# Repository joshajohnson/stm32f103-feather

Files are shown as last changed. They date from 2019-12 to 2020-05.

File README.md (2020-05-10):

# STM32F103 Feather

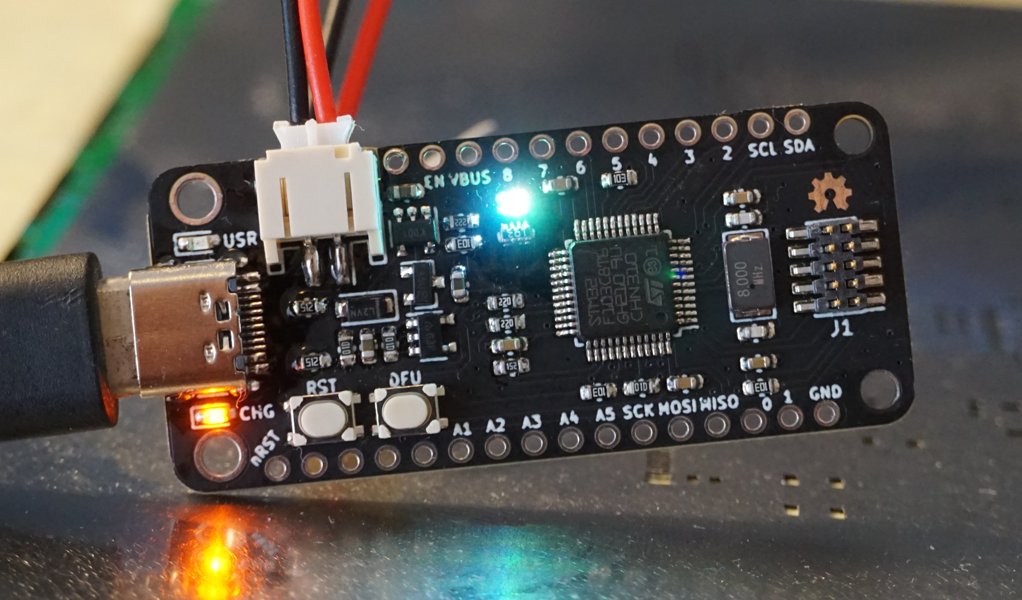
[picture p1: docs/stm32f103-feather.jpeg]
STM32F103 Feather


## STM32F103 in an Adafruit Feather form factor.
- STM32F103 MCU
- USB type C connector
- SWD Header
- RGB LED
- Designed to work with my [RF Signal Generator](https://github.com/joshajohnson/rf-sig-gen)

### TODO

#### Hardware
- [ ] Optimise pin mapping for V0.2 (SPI1 CS incorrecly positioned, may be other issues)

#### Firmware
- [ ] Improved demo code
- [ ] PWM control drivers for RGB LED
- [ ] USB Bootloader
- [ ] Add to Arduino framework with STM32Duino
- [ ] Add Black Magic Probe support?

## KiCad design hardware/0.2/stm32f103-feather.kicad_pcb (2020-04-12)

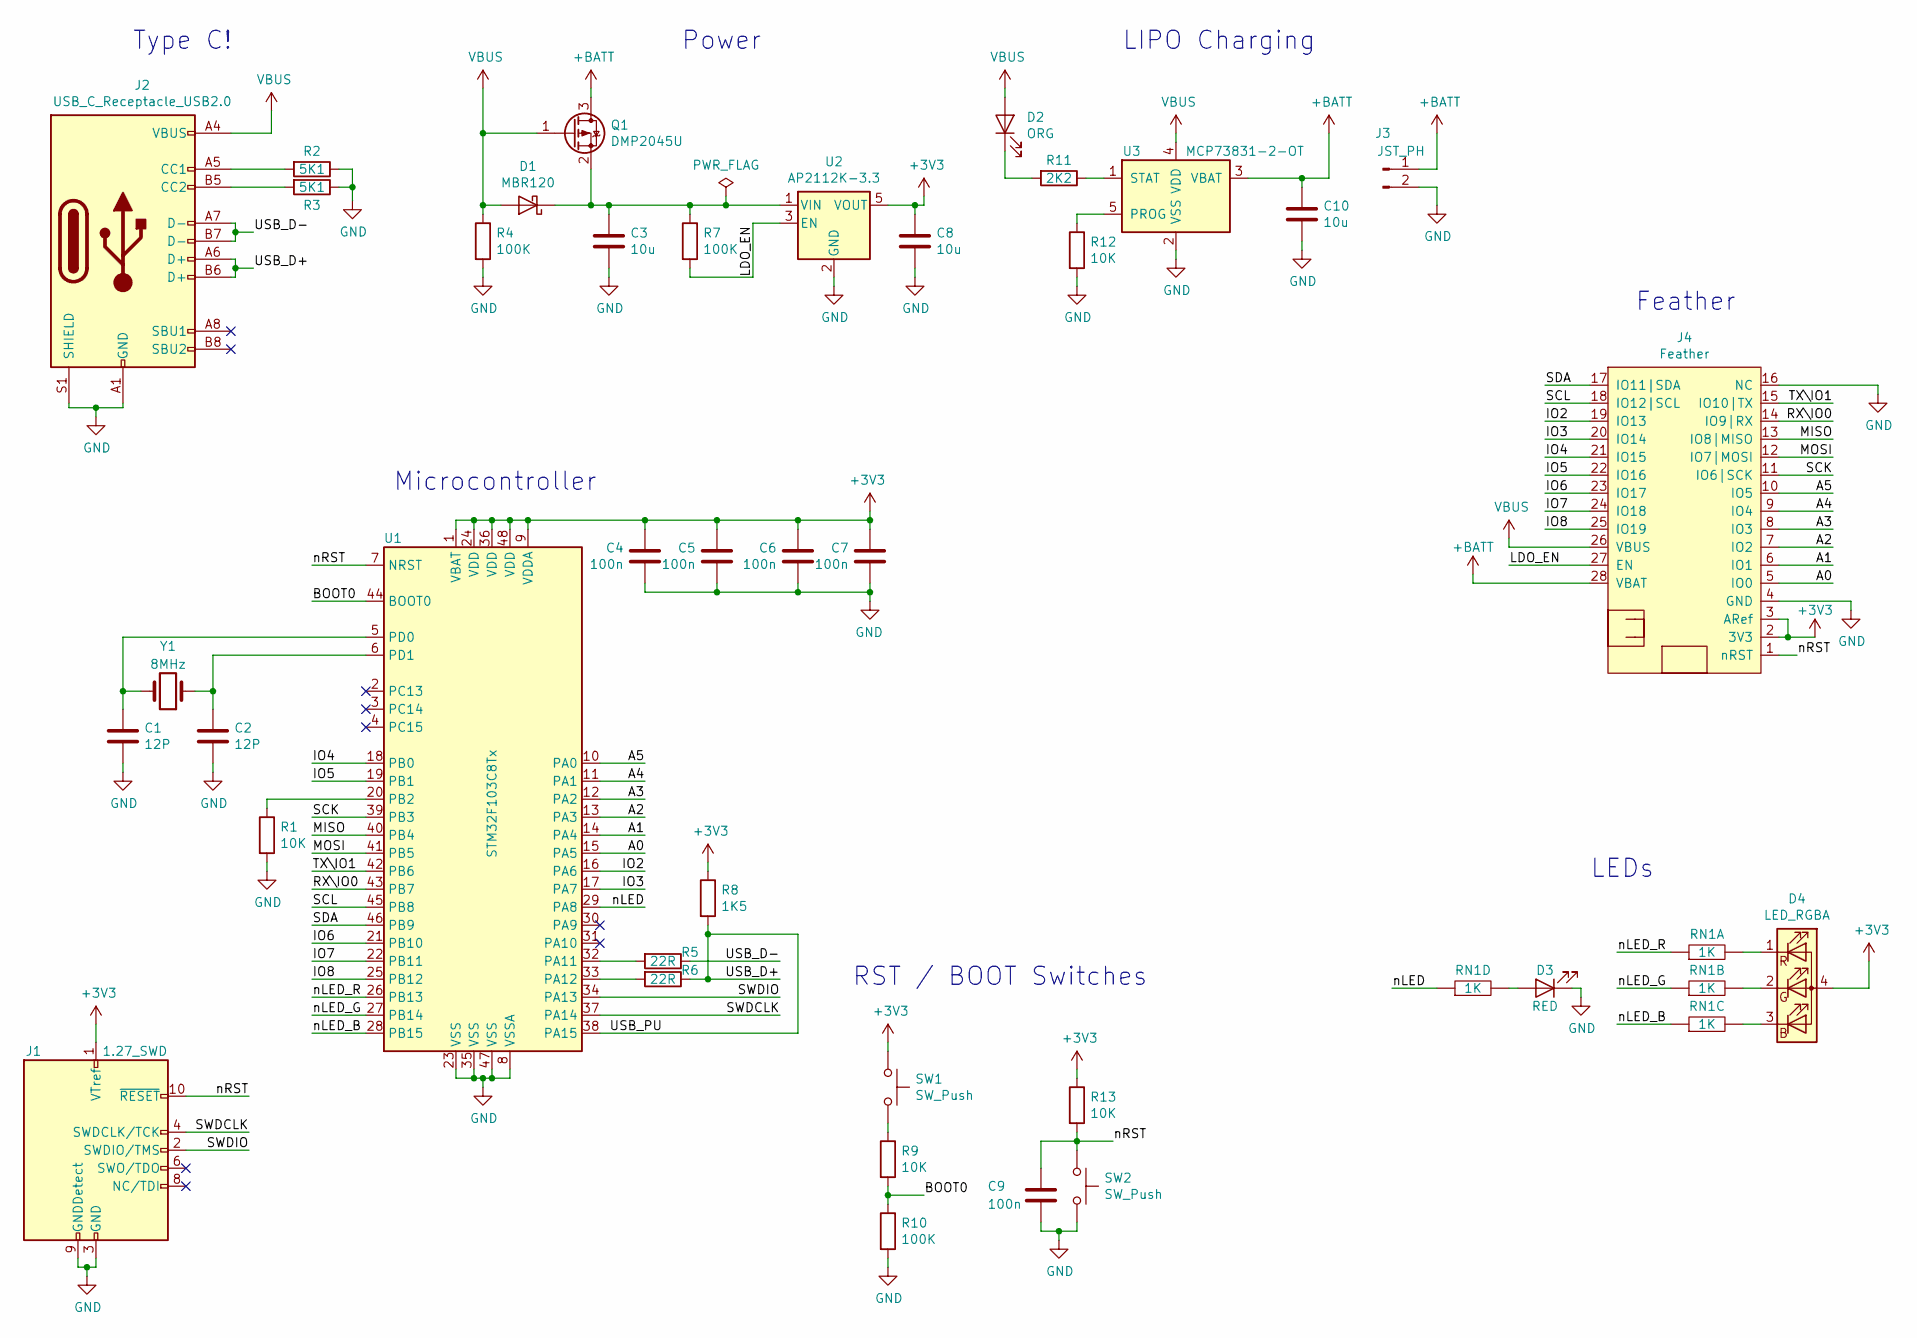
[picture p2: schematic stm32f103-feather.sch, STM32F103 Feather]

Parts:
C1, C2: 12P; C_0603_1608Metric
C3, C8, C10: 10u; C_0603_1608Metric
C4, C5, C6, C7, C9: 100n; C_0603_1608Metric
D1: MBR120; D_SOD-123FL
D2: ORG; LED_0603_1608Metric_Castellated
D3: RED; LED_0603_1608Metric_Castellated
D4: LED_RGBA; LED_0606_E6C0606RGBC3UDA
J1: 1.27_SWD; SAMTEC_FTSH-105-01-L-DV-R-TR
J2: USB_C_Receptacle_USB2.0; USB_C_Receptacle_GT-USB-7010
J3: JST_PH; JST_PH_S2B-PH-SM4-TB_1x02-1MP_P2.00mm_Horizontal
J4: Feather; featherwing-typeC
Q1: DMP2045U; SOT-23
R1, R9, R12, R13: 10K; R_0603_1608Metric
R2, R3: 5K1; R_0603_1608Metric
R4, R7, R10: 100K; R_0603_1608Metric
R5, R6: 22R; R_0603_1608Metric
R8: 1K5; R_0603_1608Metric
R11: 2K2; R_0603_1608Metric
RN1: 1K; R_Array_Convex_4x0402
SW1, SW2: SW_Push; BT_PTS815
U1: STM32F103C8Tx; LQFP-48_7x7mm_P0.5mm
U2: AP2112K-3.3; SOT-23-5
U3: MCP73831-2-OT; SOT-23-5
Y1: 8MHz; Crystal_SMD_5032-2Pin_5.0x3.2mm

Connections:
+3V3: C4.1, C5.1, C6.1, C7.1, C8.1, D4.4 (A), J1.1 (VTref), J4.2 (3V3), J4.3 (ARef), R8.1, R13.1, SW1.1, U1.1 (VBAT), U1.9 (VDDA), U1.24 (VDD), U1.36 (VDD), U1.48 (VDD), U2.5 (VOUT)
+BATT: C10.1, J3.1, J4.28 (VBAT), Q1.3 (D), U3.3 (VBAT)
/A0: J4.5 (IO0), U1.15 (PA5)
/A1: J4.6 (IO1), U1.14 (PA4)
/A2: J4.7 (IO2), U1.13 (PA3)
/A3: J4.8 (IO3), U1.12 (PA2)
/A4: J4.9 (IO4), U1.11 (PA1)
/A5: J4.10 (IO5), U1.10 (PA0)
/BOOT0: R9.2, R10.1, U1.44 (BOOT0)
/IO2: J4.19 (IO13), U1.16 (PA6)
/IO3: J4.20 (IO14), U1.17 (PA7)
/IO4: J4.21 (IO15), U1.18 (PB0)
/IO5: J4.22 (IO16), U1.19 (PB1)
/IO6: J4.23 (IO17), U1.21 (PB10)
/IO7: J4.24 (IO18), U1.22 (PB11)
/IO8: J4.25 (IO19), U1.25 (PB12)
/LDO_EN: J4.27 (EN), R7.2, U2.3 (EN)
/MISO: J4.13 (IO8|MISO), U1.40 (PB4)
/MOSI: J4.12 (IO7|MOSI), U1.41 (PB5)
/RX\IO0: J4.14 (IO9|RX), U1.43 (PB7)
/SCK: J4.11 (IO6|SCK), U1.39 (PB3)
/SCL: J4.18 (IO12|SCL), U1.45 (PB8)
/SDA: J4.17 (IO11|SDA), U1.46 (PB9)
/SWDCLK: J1.4 (SWDCLK/TCK), U1.37 (PA14)
/SWDIO: J1.2 (SWDIO/TMS), U1.34 (PA13)
/TX\IO1: J4.15 (IO10|TX), U1.42 (PB6)
/USB_D+: J2.A6 (D+), J2.B6 (D+), R6.1, R8.2, U1.38 (PA15)
/USB_D-: J2.A7 (D-), J2.B7 (D-), R5.1
/nLED: RN1.1, U1.29 (PA8)
/nLED_B: RN1.2, U1.28 (PB15)
/nLED_G: RN1.3, U1.27 (PB14)
/nLED_R: RN1.4, U1.26 (PB13)
/nRST: C9.1, J1.10 (~RESET~), J4.1 (nRST), R13.2, SW2.1, U1.7 (NRST)
GND: C1.2, C2.2, C3.2, C4.2, C5.2, C6.2, C7.2, C8.2, C9.2, C10.2, D3.1 (K), J1.3 (GND), J1.5 (GND), J1.9 (GNDDetect), J2.A1 (GND), J2.A12 (GND), J2.B1 (GND), J2.B12 (GND), J2.S1 (SHIELD), J3.2, J4.4 (GND), J4.16 (NC), R1.2, R2.1, R3.1, R4.2, R10.2, R12.2, SW2.2, U1.8 (VSSA), U1.23 (VSS), U1.35 (VSS), U1.47 (VSS), U2.2 (GND), U3.2 (VSS)
unnamed: C1.1, U1.5 (PD0), Y1.2
unnamed: C2.1, U1.6 (PD1), Y1.1
unnamed: C3.1, D1.1 (K), Q1.2 (S), R7.1, U2.1 (VIN)
unnamed: D2.1 (K), R11.2
unnamed: D3.2 (A), RN1.8
unnamed: D4.1 (RK), RN1.5
unnamed: D4.2 (GK), RN1.6
unnamed: D4.3 (BK), RN1.7
unnamed: J2.A5 (CC1), R2.2
unnamed: J2.B5 (CC2), R3.2
unnamed: R1.1, U1.20 (PB2)
unnamed: R5.2, U1.32 (PA11)
unnamed: R6.2, U1.33 (PA12)
unnamed: R9.1, SW1.2
unnamed: R11.1, U3.1 (STAT)
unnamed: R12.1, U3.5 (PROG)
VBUS: D1.2 (A), D2.2 (A), J2.A4 (VBUS), J2.A9 (VBUS), J2.B4 (VBUS), J2.B9 (VBUS), J4.26 (VBUS), Q1.1 (G), R4.1, U3.4 (VDD)

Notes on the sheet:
RST / BOOT Switches
Feather
Microcontroller
Type C!
Power
LIPO Charging
LEDs

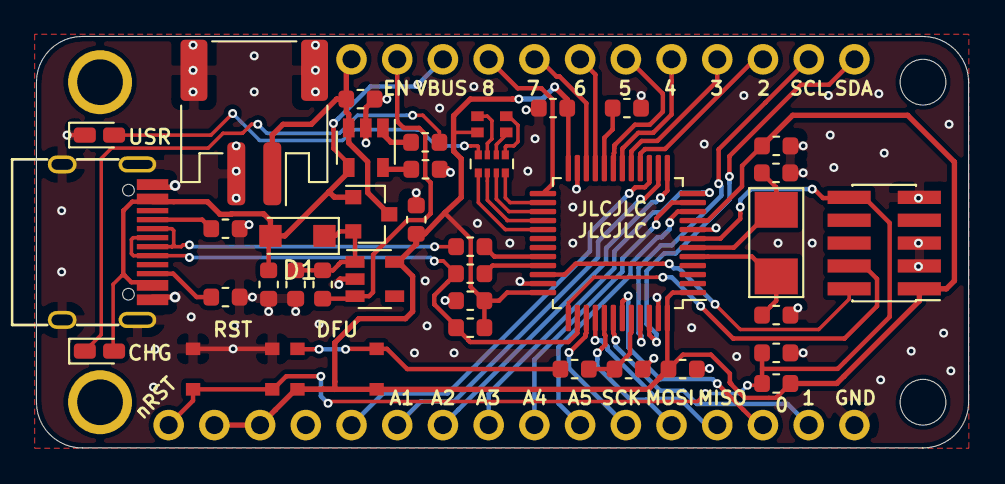
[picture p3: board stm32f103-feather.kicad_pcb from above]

Board: 2 copper layers, 51.8 x 22.9 mm, 39 parts (0 on the bottom side), 51 nets.

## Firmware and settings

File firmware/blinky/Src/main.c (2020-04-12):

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

/* Includes ------------------------------------------------------------------*/
#include "main.h"
#include "gpio.h"


void SystemClock_Config(void);
/**
  * @brief  The application entry point.
  * @retval int
  */
int main(void)
{
  

  /* MCU Configuration--------------------------------------------------------*/

  /* Reset of all peripherals, Initializes the Flash interface and the Systick. */
  HAL_Init();

  /* Configure the system clock */
  SystemClock_Config();

  /* Initialize all configured peripherals */
  MX_GPIO_Init();
  /* USER CODE BEGIN 2 */
  HAL_GPIO_WritePin(LED_nRED_GPIO_Port, LED_nRED_Pin,1);
  HAL_GPIO_WritePin(LED_nGRN_GPIO_Port, LED_nGRN_Pin,1);
  HAL_GPIO_WritePin(LED_nBLU_GPIO_Port, LED_nBLU_Pin,1);
  HAL_GPIO_WritePin(LED_nUSR_GPIO_Port, LED_nUSR_Pin,1);

  /* USER CODE END 2 */

  /* Infinite loop */
  /* USER CODE BEGIN WHILE */
  while (1)
  {
    HAL_GPIO_TogglePin(LED_nRED_GPIO_Port, LED_nRED_Pin);
    HAL_Delay(500);
    HAL_GPIO_TogglePin(LED_nGRN_GPIO_Port, LED_nGRN_Pin);
    HAL_Delay(500);
    HAL_GPIO_TogglePin(LED_nBLU_GPIO_Port, LED_nBLU_Pin);
    HAL_Delay(500);
    HAL_GPIO_TogglePin(LED_nUSR_GPIO_Port, LED_nUSR_Pin);
    HAL_Delay(500);
    /* USER CODE END WHILE */

    /* USER CODE BEGIN 3 */
  }
  /* USER CODE END 3 */
}

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


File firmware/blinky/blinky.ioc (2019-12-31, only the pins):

Mcu.UserName=STM32F103C8Tx
PA13.Signal=SYS_JTMS-SWDIO
PA14.Signal=SYS_JTCK-SWCLK
PA8.GPIO_Label=LED_nUSR
PA8.Signal=GPIO_Output
PB13.GPIO_Label=LED_nRED
PB13.Signal=GPIO_Output
PB14.GPIO_Label=LED_nGRN
PB14.Signal=GPIO_Output
PB15.GPIO_Label=LED_nBLU
PB15.Signal=GPIO_Output
PD0-OSC_IN.Signal=RCC_OSC_IN
PD1-OSC_OUT.Signal=RCC_OSC_OUT

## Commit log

2019-12-17 change osc footprint
    [stm32f103-feather.kicad_pcb]
2019-12-18 generated gerbers for V0.1
    [stm32f103-feather.kicad_pcb]
2020-04-12 board changes
    [stm32f103-feather.kicad_pcb, stm32f103-feather.sch]
2020-04-12 schematic things
    [stm32f103-feather.sch]
2020-04-12 uart working
2020-04-13 bitbang spi appears to work
    [stm32f103-feather.kicad_pcb, stm32f103-feather.sch]
2020-04-19 rf working, leds not

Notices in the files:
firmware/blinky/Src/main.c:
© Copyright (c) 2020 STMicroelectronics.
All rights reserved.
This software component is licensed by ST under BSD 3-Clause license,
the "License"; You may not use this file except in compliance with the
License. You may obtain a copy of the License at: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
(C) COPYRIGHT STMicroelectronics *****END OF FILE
